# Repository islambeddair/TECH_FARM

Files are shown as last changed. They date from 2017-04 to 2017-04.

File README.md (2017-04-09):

# TECH_FARMMoisture Sensor

General Overview:
Soil moisture sensor measure the volumetric water content in soil. Since the direct gravimetric measurement of free soil moisture requires removing, drying, and weighting of a sample, soil moisture sensors measure the volumetric water content indirectly by using some other property of the soil, such as electrical resistance, dielectric constant, or interaction with neutrons, as a proxy for the moisture content. The relation between the measured property and soil moisture must be calibrated and may vary depending on environmental factors such as soil type, temperature, or electric conductivity. Reflected microwave radiation is affected by the soil moisture and is used for remote sensing in hydrology and agriculture. Portable probe instruments can be used by farmers or gardeners.
Applications:
Agriculture:
Measuring soil moisture is important for agricultural applications to help farmers manage their irrigation systems more efficiently. Knowing the exact soil moisture conditions on their fields, not only are farmers able to generally use less water to grow a crop, they are also able to increase yields and the quality of the crop by improved management of soil moisture during critical plant growth stages.
Landscape irrigation:
In urban and suburban areas, landscapes and residential lawns are using soil moisture sensors to interface with an irrigation controller. Connecting a soil moisture sensor to a simple irrigation clock will convert it into a "smart" irrigation controller that prevents irrigation cycles when the soil is already wet, e.g. following a recent rainfall event.
Golf courses are using soil moisture sensors to increase the efficiency of their irrigation systems to prevent over-watering and leaching of fertilizers and other chemicals into the ground.
Research:
Soil moisture sensors are used in numerous research applications, e.g. in agricultural science and horticulture including irrigation planning, climate research, or environmental science including solute transport studies and as auxiliary sensors for soil respiration measurements.

	We will use moisture sensor in agricultural applications. 
Hardware Overview:
The Soil Moisture Sensor is pretty straightforward when it comes to hookup. You need to supply VCC and GND. We recommend not powering the sensor constantly to prevent oxidation of the probes (more on this in a bit). You will get a SIG out, which will be between almost VCC and GND, depending on the amount of water in the soil. The two probes are acting as a variable resistor – more water in the soil means better conductivity and results in a lower resistance and a higher SIG out. Your analog readings will vary depending on what voltage you use for Vcc as well as the resolution of your ADC pins.

First: design the moisture sensor by using EAGLE program.

•	EAGLE schematic for moisture sensor.

•	EAGLE board for moisture sensor.

Second:  made (PCB) for moisture sensor.
 
•	Moisture sensor

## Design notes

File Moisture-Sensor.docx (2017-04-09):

Moisture Sensor

General Overview:

Soil moisture sensor measure the volumetric water content in soil. Since the direct gravimetric measurement of free soil moisture requires removing, drying, and weighting of a sample, soil moisture sensors measure the volumetric water content indirectly by using some other property of the soil, such as electrical resistance, dielectric constant, or interaction with neutrons, as a proxy for the moisture content. The relation between the measured property and soil moisture must be calibrated and may vary depending on environmental factors such as soil type, temperature, or electric conductivity. Reflected microwave radiation is affected by the soil moisture and is used for remote sensing in hydrology and agriculture. Portable probe instruments can be used by farmers or gardeners.

## Applications:

### Agriculture:

Measuring soil moisture is important for agricultural (https://en.wikipedia.org/wiki/Agriculture) applications to help farmers manage their irrigation systems (https://en.wikipedia.org/wiki/Irrigation_system) more efficiently. Knowing the exact soil moisture conditions on their fields, not only are farmers able to generally use less water to grow a crop, they are also able to increase yields and the quality of the crop by improved management of soil moisture during critical plant growth stages.

### Landscape irrigation:

In urban (https://en.wikipedia.org/wiki/Urban_area) and suburban (https://en.wikipedia.org/wiki/Suburban) areas, landscapes (https://en.wikipedia.org/wiki/Garden) and residential lawns (https://en.wikipedia.org/wiki/Lawn) are using soil moisture sensors to interface with an irrigation controller. Connecting a soil moisture sensor to a simple irrigation clock will convert it into a "smart" irrigation controller that prevents irrigation cycles when the soil is already wet, e.g. following a recent rainfall event.

Golf courses are using soil moisture sensors to increase the efficiency of their irrigation systems to prevent over-watering and leaching of fertilizers and other chemicals into the ground.

### Research:

Soil moisture sensors are used in numerous research applications, e.g. in agricultural science (https://en.wikipedia.org/wiki/Agricultural_science) and horticulture (https://en.wikipedia.org/wiki/Horticulture) including irrigation planning, climate research (https://en.wikipedia.org/wiki/Climatology), or environmental science (https://en.wikipedia.org/wiki/Environmental_science) including solute (https://en.wikipedia.org/wiki/Solution) transport studies and as auxiliary sensors for soil respiration (https://en.wikipedia.org/wiki/Soil_respiration) measurements.

- We will use moisture sensor in agricultural (https://en.wikipedia.org/wiki/Agriculture) applications.

## Hardware Overview:

The Soil Moisture Sensor is pretty straightforward when it comes to hookup. You need to supply VCC and GND. We recommend not powering the sensor constantly to prevent oxidation of the probes (more on this in a bit). You will get a SIG out, which will be between almost VCC and GND, depending on the amount of water in the soil. The two probes are acting as a variable resistor – more water in the soil means better conductivity and results in a lower resistance and a higher SIG out. Your analog readings will vary depending on what voltage you use for Vcc as well as the resolution of your ADC pins.

## First: design the moisture sensor by using EAGLE program.

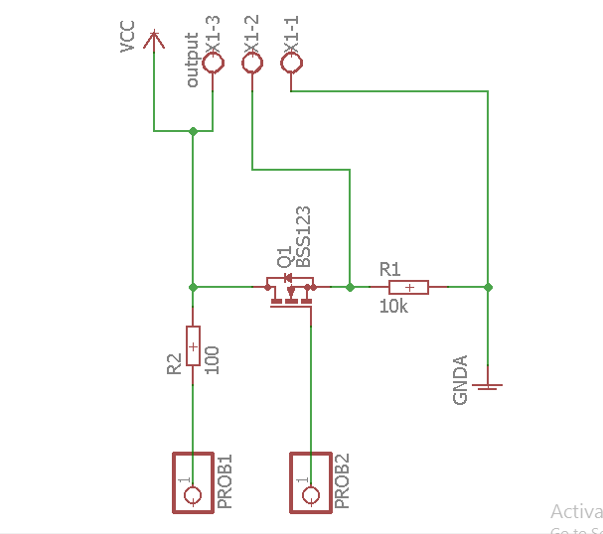
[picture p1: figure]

## EAGLE schematic for moisture sensor.

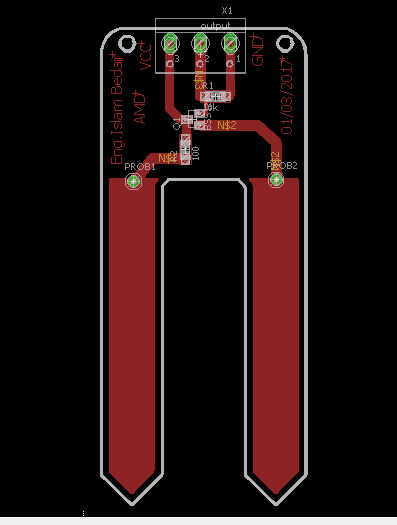
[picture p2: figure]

## EAGLE board for moisture sensor.

## Second: made (PCB) for moisture sensor.

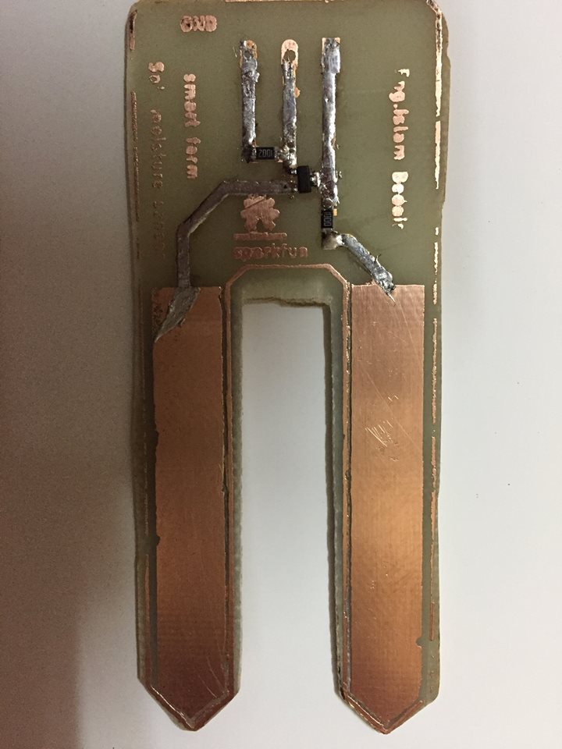
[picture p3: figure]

- Moisture sensor

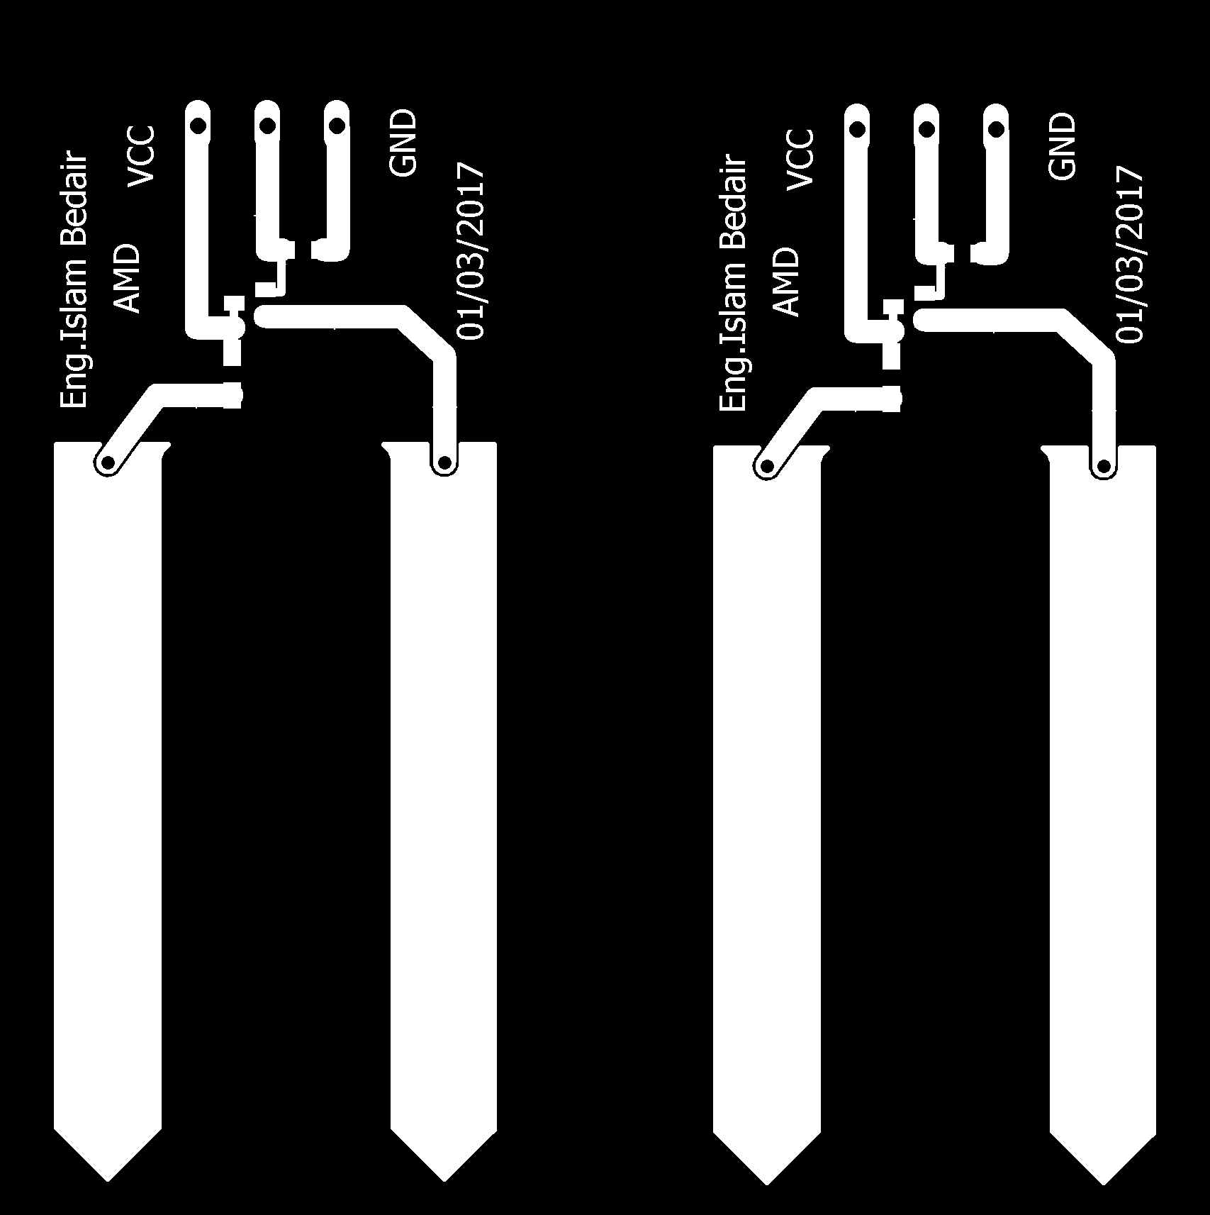
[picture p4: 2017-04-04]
soil.png

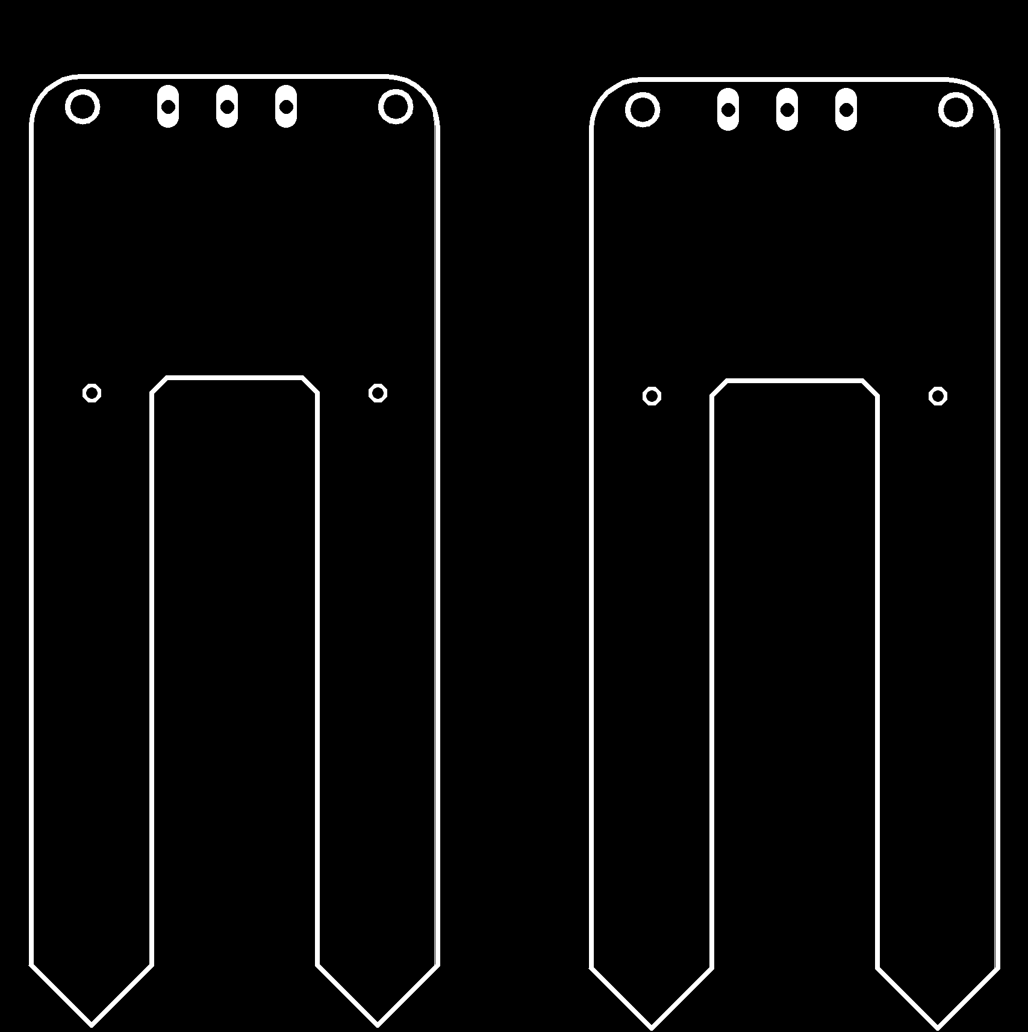
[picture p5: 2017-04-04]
soil cut.png

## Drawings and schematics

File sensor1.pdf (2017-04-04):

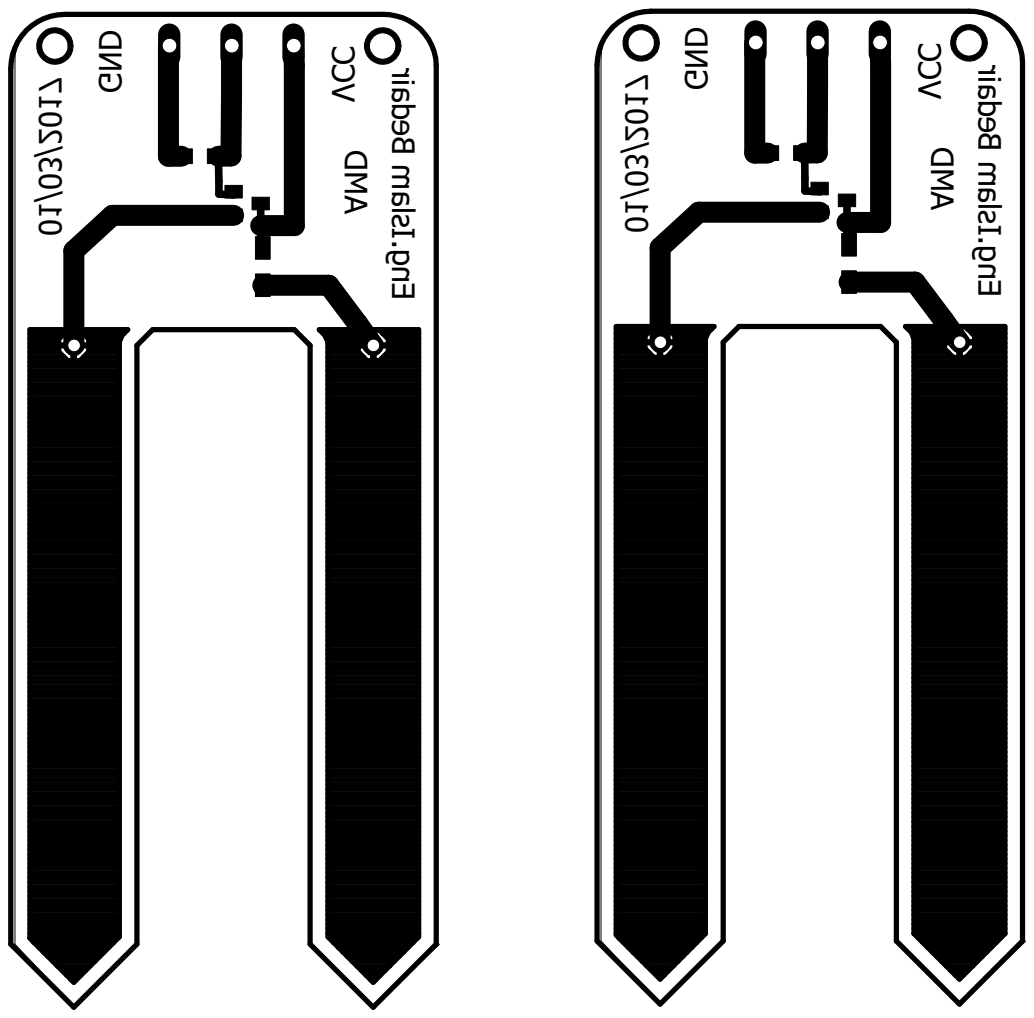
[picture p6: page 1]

Eng.Islam BedairGND VCC AMD 01/03/2017

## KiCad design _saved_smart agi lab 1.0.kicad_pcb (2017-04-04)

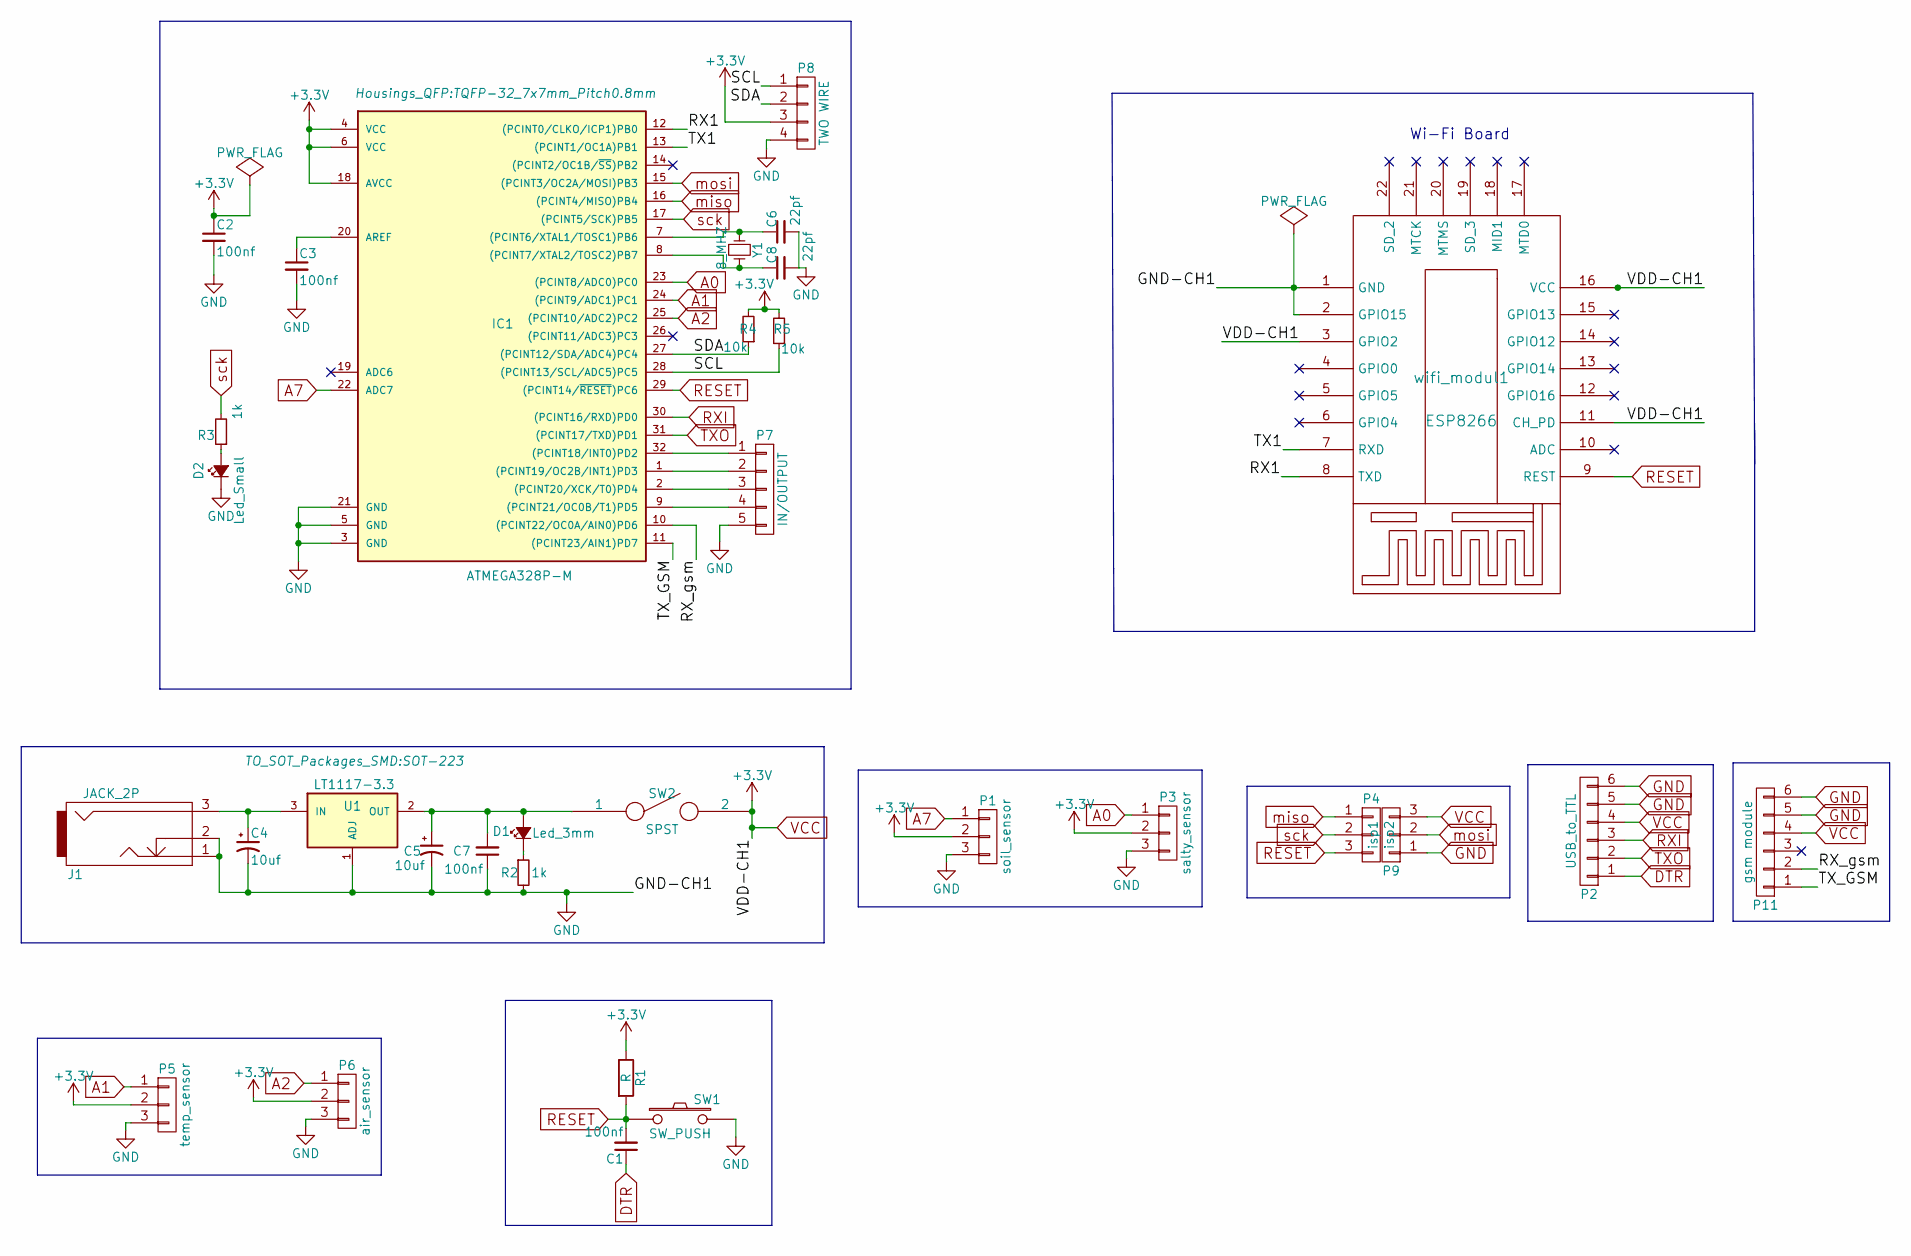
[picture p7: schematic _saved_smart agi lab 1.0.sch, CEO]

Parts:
C1: 100nf; C_Disc_D7.0mm_W2.5mm_P5.00mm
C2, C3, C7: 100nf; C_1206_HandSoldering
C4, C5: 10uf; C_1206_HandSoldering
C6, C8: 22pf; C_Disc_D3.0mm_W2.0mm_P2.50mm
D1: Led_3mm; LED_D3.0mm
D2: Led_Small; LED_D3.0mm
IC1: ATMEGA328P-M; TQFP-32_7x7mm_Pitch0.8mm
J1: JACK_2P; BARREL_JACK
P1: soil_sensor; AK300-3
P2: USB_to_TTL; Pin_Header_Straight_1x06_Pitch2.54mm
P3: salty_sensor; AK300-3
P4: isp2; Pin_Header_Straight_1x03_Pitch2.54mm
P5: temp_sensor; AK300-3
P6: air_sensor; AK300-3
P7: IN/OUTPUT; Pin_Header_Straight_1x05_Pitch2.54mm
P8: TWO WIRE; Pin_Header_Straight_1x04_Pitch2.54mm
P9: isp1; Pin_Header_Straight_1x03_Pitch2.54mm
P11: gsm module; Pin_Header_Straight_1x06_Pitch2.54mm
R1: R; R_1206_HandSoldering
R2, R3: 1k; R_1206_HandSoldering
R4, R5: 10k; R_1206_HandSoldering
SW1: SW_PUSH; SW_PUSH_6mm_h4.3mm
SW2: SPST; SW_PUSH_x2
U1: LT1117-3.3; SOT-223
Y1: 8_MHZ; Resonator-2pin_w7.0mm_h2.5mm
wifi_modul1: ESP8266; esp12

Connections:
/RX1: IC1.12 ((PCINT0/CLKO/ICP1)PB0), wifi_modul1.8 (TXD)
/RX_gsm: IC1.10 ((PCINT22/OC0A/AIN0)PD6), P11.2
/SCL: IC1.28 ((PCINT13/SCL/ADC5)PC5), P8.1, R5.1
/SDA: IC1.27 ((PCINT12/SDA/ADC4)PC4), P8.2, R4.1
/TX1: IC1.13 ((PCINT1/OC1A)PB1), wifi_modul1.7 (RXD)
/TX_GSM: IC1.11 ((PCINT23/AIN1)PD7), P11.1
A0: IC1.23 ((PCINT8/ADC0)PC0), P3.1
A1: IC1.24 ((PCINT9/ADC1)PC1), P5.1
A2: IC1.25 ((PCINT10/ADC2)PC2), P6.1
A7: IC1.22 (ADC7), P1.1
DTR: C1.1, P2.1
GND: C2.2, C3.2, C4.2, C5.2, C6.2, C7.1, C8.2, D2.1 (K), IC1.3 (GND), IC1.5 (GND), IC1.21 (GND), J1.1, J1.2, P1.3, P2.5, P2.6, P3.3, P5.3, P6.3, P7.5, P8.4, P9.1, P11.5, P11.6, R2.2, SW1.2, U1.1 (ADJ), wifi_modul1.1 (GND), wifi_modul1.2 (GPIO15)
unnamed: C3.1, IC1.20 (AREF)
unnamed: C4.1, J1.3, U1.3 (IN)
unnamed: C5.1, C7.2, D1.2 (A), SW2.1, U1.2 (OUT)
unnamed: C6.1, IC1.7 ((PCINT6/XTAL1/TOSC1)PB6), Y1.1
unnamed: C8.1, IC1.8 ((PCINT7/XTAL2/TOSC2)PB7), Y1.2
unnamed: D1.1 (K), R2.1
unnamed: D2.2 (A), R3.1
unnamed: IC1.1 ((PCINT19/OC2B/INT1)PD3), P7.2
unnamed: IC1.2 ((PCINT20/XCK/T0)PD4), P7.3
unnamed: IC1.9 ((PCINT21/OC0B/T1)PD5), P7.4
unnamed: IC1.32 ((PCINT18/INT0)PD2), P7.1
RESET: C1.2, IC1.29 ((PCINT14/~RESET~)PC6), P4.3, R1.2, SW1.1, wifi_modul1.9 (REST)
RXI: IC1.30 ((PCINT16/RXD)PD0), P2.3
TXO: IC1.31 ((PCINT17/TXD)PD1), P2.2
VCC: C2.1, IC1.4 (VCC), IC1.6 (VCC), IC1.18 (AVCC), P1.2, P2.4, P3.2, P5.2, P6.2, P8.3, P9.3, P11.4, R1.1, R4.2, R5.2, SW2.2, wifi_modul1.3 (GPIO2), wifi_modul1.11 (CH_PD), wifi_modul1.16 (VCC)
miso: IC1.16 ((PCINT4/MISO)PB4), P4.1
mosi: IC1.15 ((PCINT3/OC2A/MOSI)PB3), P9.2
sck: IC1.17 ((PCINT5/SCK)PB5), P4.2, R3.2

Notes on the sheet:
Wi-Fi Board

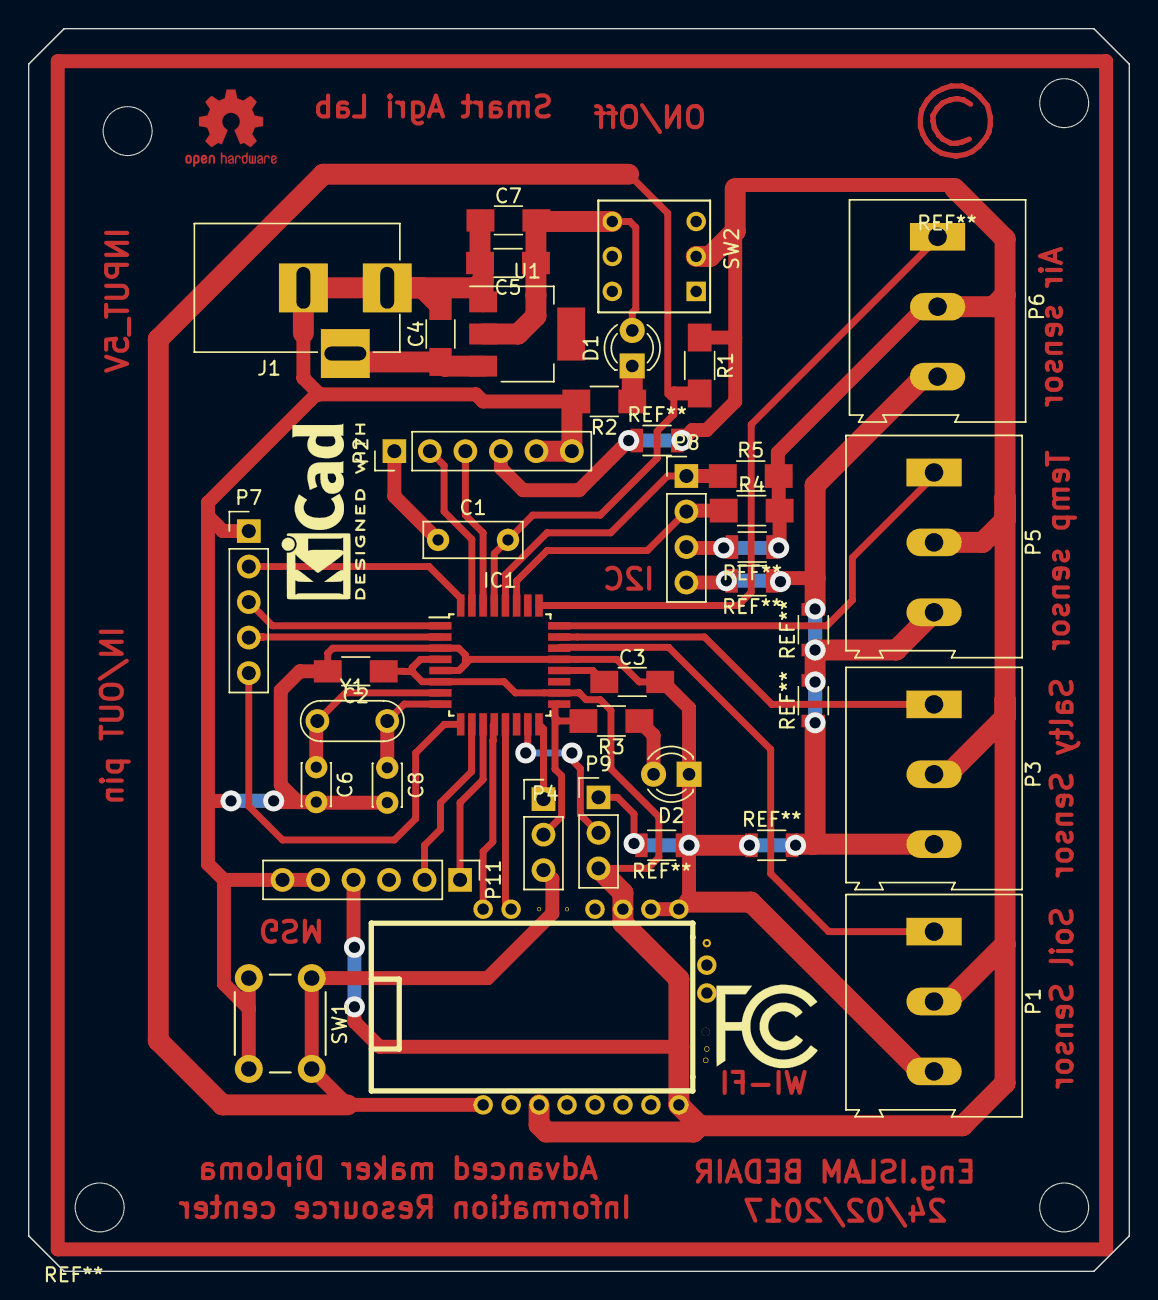
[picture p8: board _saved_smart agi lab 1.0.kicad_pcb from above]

Board: 2 copper layers, 78.7 x 88.9 mm, 32 parts (0 on the bottom side), 30 nets.

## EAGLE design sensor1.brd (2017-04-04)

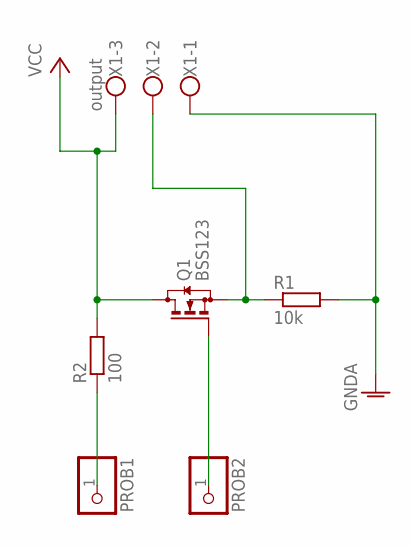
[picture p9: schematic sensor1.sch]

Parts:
PROB1, PROB2: PINHD-1X1; 1X01
Q1: BSS123; SOT23
R1: 10k; R1206W
R2: 100; R1206W
X1: output; W237-103

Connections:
GNDA: R1.2, X1.1
unnamed: PROB1.1, R2.1
unnamed: PROB2.1, Q1.1 (G)
unnamed: Q1.2 (S), R1.1, X1.2
VCC: Q1.3 (D), R2.2, X1.3

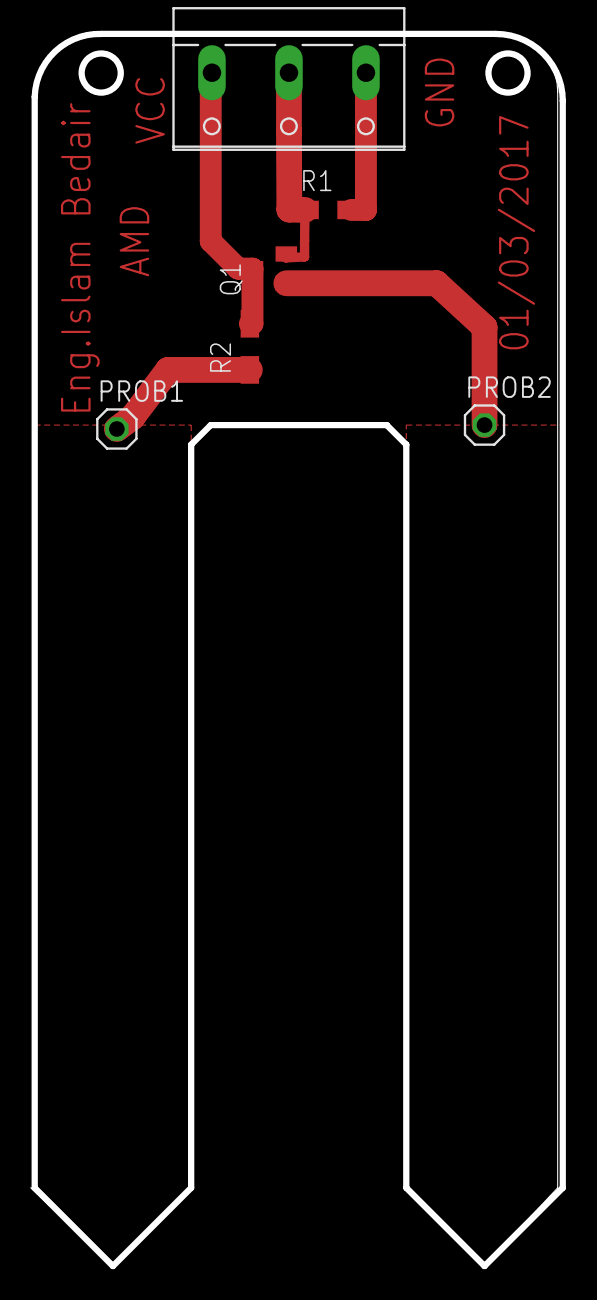
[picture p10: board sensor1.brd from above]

Board: 2 copper layers, 34.3 x 80.0 mm, 6 parts (0 on the bottom side), 5 nets.

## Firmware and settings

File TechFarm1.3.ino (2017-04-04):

#include <SoftwareSerial.h>#include <Adafruit_Sensor.h>
#include <DHT.h>
#include <DHT_U.h>
#define DHTPIN            A2         // Pin which is connected to the DHT sensor.
#define DHTTYPE           DHT11    // comment the type of sensor in use: DHT 11
// See guide for details on sensor wiring and usage:
//   https://learn.adafruit.com/dht/overview
DHT_Unified dht(DHTPIN, DHTTYPE);
uint32_t delayMS;
//Wifi connection
SoftwareSerial mySerial(9, 8); // RX, TX
#define SSID "Connectify-me" //FLE Co-Working Space
#define PASS "syxaxot2" //FablabNetworkCO
#define IP "api.thingspeak.com" // thingspeak.com
String url = "/update?key=KMNWD732HF26P0BN&field1="; //thingspeak channel
//taking readings
void setup() {
  mySerial.begin(9600); // for arduino pro mini 8MH 3.3V
  Serial.begin(9600); //for serial port
 //Initialization of WiFi module 
   dht.begin();
  // Print temperature sensor details.
  sensor_t sensor;
  dht.temperature().getSensor(&sensor);
  dht.humidity().getSensor(&sensor);
  //delay(4000);
  while (mySerial.available() > 0)
    //Serial.read();
    delay(1000);
  Serial.println("AT"); //Testing module
  mySerial.println("AT");
  if (mySerial.find("OK"))
  {
    Serial.println("Module is ready");
  }
  else
  {
    Serial.println("Module have no response.");
  }
  mySerial.println("AT+CWMODE=1"); // SETTING mode
  Serial.println("AT+CWMODE=1");
  delay(200);
  if (mySerial.find("OK"))
  {
    Serial.println("Mode set");
  }
  else
  {
    Serial.println("Module have no response.");
  }
  while (mySerial.find("OK") == false)
  {
    String wifi = "AT+CWJAP=\"";
    wifi += SSID;
    wifi += "\",\"";
    wifi += PASS;
    wifi += "\"";
    Serial.println(wifi);
    mySerial.println(wifi);
    delay(5000);
  }
  Serial.println("Connected");
  mySerial.println("AT+CIPMUX=1"); // changing mode
  Serial.println("AT+CIPMUX=1");
  delay(200);
  if (mySerial.find("OK"))
  {
    Serial.println("Mode set");
  }
  else
  {
    Serial.println("Module have no response.");
  }
  Serial.print("Connecting to ");
  Serial.println(IP);
  while (mySerial.find("OK") == false)
  {
    String page = "AT+CIPSTART=4,\"TCP\",\"";
    page += IP;
    page += "\",80";
    mySerial.println(page);
    Serial.println(page);
    delay(5000);
  }
  Serial.println("Linked");
// Initialize device DH11.
/*
  Serial.println("DHT11 Unified Sensor Example");
  Serial.println("------------------------------------");
  Serial.println("Temperature");
  Serial.print  ("Sensor:       "); Serial.println(sensor.name);
  Serial.print  ("Driver Ver:   "); Serial.println(sensor.version);
  Serial.print  ("Unique ID:    "); Serial.println(sensor.sensor_id);
  Serial.print  ("Max Value:    "); Serial.print(sensor.max_value); Serial.println(" *C");
  Serial.print  ("Min Value:    "); Serial.print(sensor.min_value); Serial.println(" *C");
  Serial.print  ("Resolution:   "); Serial.print(sensor.resolution); Serial.println(" *C");  
  Serial.println("------------------------------------");
  // Print humidity sensor details.
  
  Serial.println("------------------------------------");
  Serial.println("Humidity");
  Serial.print  ("    Sensor:       "); Serial.println(sensor.name);
  Serial.print  ("Driver Ver:   "); Serial.println(sensor.version);
  Serial.print  (" Unique ID:    "); Serial.println(sensor.sensor_id);
  Serial.print  (" Max Value:    "); Serial.print(sensor.max_value); Serial.println("%");
  Serial.print  (" Min Value:    "); Serial.print(sensor.min_value); Serial.println("%");
  Serial.print  ("Resolution:   "); Serial.print(sensor.resolution); Serial.println("%");  
  Serial.println("------------------------------------");
  // Set delay between sensor readings based on sensor details.
  */
  delayMS = sensor.min_delay / 1000;
  
}
void loop() {
  // Delay between measurements.
  delay(delayMS);
  // Get temperature event and print its value.
  sensors_event_t event;  
  dht.temperature().getEvent(&event);
  if (isnan(event.temperature)) {
    Serial.println("Error reading temperature!");
  }
  else {
    Serial.print("Temperature: ");
    Serial.print(event.temperature);
    Serial.println(" *C");
  }
  // Get humidity event and print its value.
  dht.humidity().getEvent(&event);
  if (isnan(event.relative_humidity)) {
    Serial.println("Error reading humidity!");
  }
  else {
    Serial.print("Humidity: ");
    Serial.print(event.relative_humidity);
    Serial.println("%");
  }
  int x = analogRead(A1);
  //Cloud
  String cmd = "GET ";
  cmd += url;
  cmd += x;
  cmd += " HTTP/1.0\r\n\r\n";
  Serial.print("AT+CIPSEND=4,");//determine how many bytes
  Serial.println(cmd.length());
  mySerial.print("AT+CIPSEND=4,");
  mySerial.println(cmd.length());
  if (mySerial.find("OK"))
  {
    Serial.println("OK");
  } else {
    Serial.println("ERROR");
  }
  mySerial.print(cmd);//send request
  delay(250);
  // delay bta3 el channel 300
  while (mySerial.available())
  {
    char c = mySerial.read();
    Serial.write(c);
    if (c == '\r') Serial.print('\n');
  }
  Serial.println("\r\n.............................");
  delay(5000);
  while (mySerial.find("OK") == false)
  {
    String page = "AT+CIPSTART=4,\"TCP\",\"";
    page += IP;
    page += "\",80";
    mySerial.println(page);
    Serial.println(page);
    delay(7000);
  }
  Serial.println("Linked");
}
